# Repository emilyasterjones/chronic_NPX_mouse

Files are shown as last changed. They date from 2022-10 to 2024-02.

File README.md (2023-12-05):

# chronic_NPX_mouse
Build files for chronic, recoverable Neuropixels 1.0 or 2.0 implants in mice. Used in [this protocol collection](dx.doi.org/10.17504/protocols.io.e6nvwjo87lmk/v2).

Chronic recoverable implant based off of [(Juavinett et al, 2019)](https://elifesciences.org/articles/47188) and modified by Janna Aarse, who generously shared her build files with me to modify.

**Components**
* Body piece (single for 1.0 probes, left and right for dual 2.0 probes)
* Wing (attaches to body with screw & nut)
* Flex holders (go around the PCB and lower part of flex cable)
* Dome (covers side of shanks opposite the wings)
* Headstage holder
* **NEW** Lower profile headstage holder (see 2.1 design folder). This holder sits behind the implant, so the attachments during surgery are substantially shorter (at the expense of losing LED tracking). The holder is mounted during surgery (adds .14g), and you can choose to attach the headstage during surgery as well (adds a total of 1.04g). During recording, simply plug in the Omnetics connector. Optionally, hook a paper clip (attached to a counterweighted pulley) into the hole to relieve some of the weight during recording.

**Versions**
* Single 1.0 probe
* Dual 2.0 beta probes
* Dual 2.0 probes (same as beta probe files, just with updated flex holders and headstage holder by Frances Cho and probe + headstage files from Neuropixels)
* 2.1 design (same as 2.0 builds, but I will be updating these files over time as I test new versions). 

**Possible modifications**
* If you don't need LED tracking, you can remove the arms of the headstage holder.
* Body pieces can attach to either side of the probe and at any height. You can also mount the body pieces at any angle, though the wing pieces are rounded so that angling the body piece is unnecessary, even at extreme angles of insertion.
* All flex holders, except for flex holder #1 (with tab slot), are optional. If your probes are very close together, you can skip the flex holders (except holder #1) and just cover the wires and PCB with electrical tape.
* If your probes are angled towards each other such that the body pieces might collide, you can (1) attach a dovetail as a shim under the body piece to move it away, (2) mount the body piece farther to the side of the probe, or (3) angle the wing holder portion away from the probe. See the angled body piece example in the 2.0 probe folder.

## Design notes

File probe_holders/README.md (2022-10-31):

Dovetail cap made to official Neuropixels specs: https://e2f49b05-3010-45e2-a7bf-b8f67811425a.filesusr.com/ugd/832f20_1617705787d84f7795ec85aa08630ea1.pdf

NOTE: the machined dovetail holder adapter is the inverted; should be a tapped hole not an outward screw

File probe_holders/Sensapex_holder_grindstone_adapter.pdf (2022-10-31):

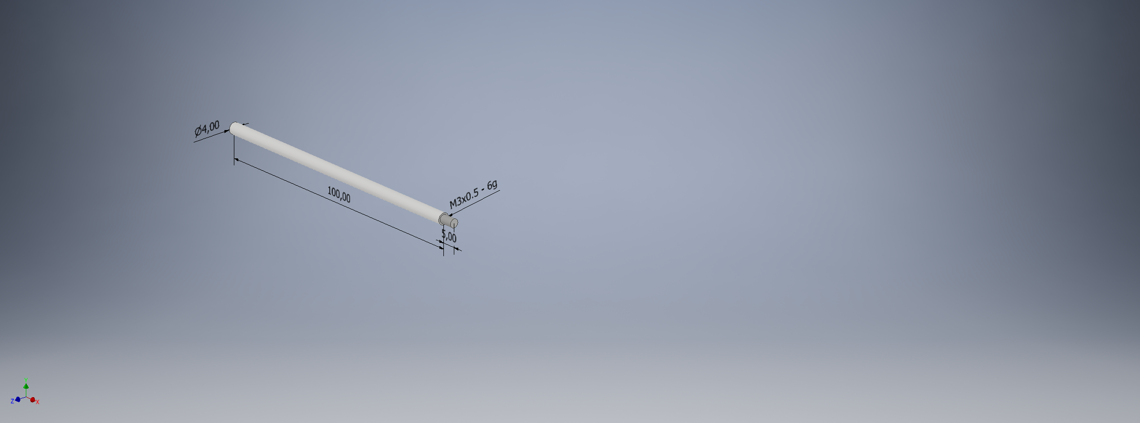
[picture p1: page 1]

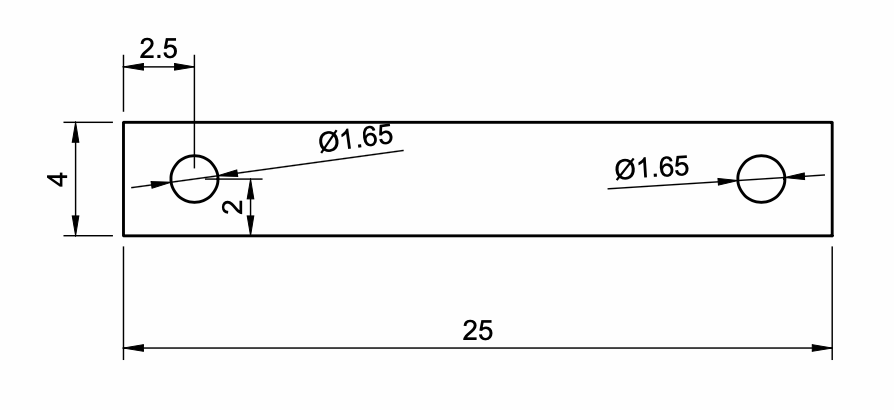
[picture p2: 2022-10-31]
accessories/Headbar_specs.png

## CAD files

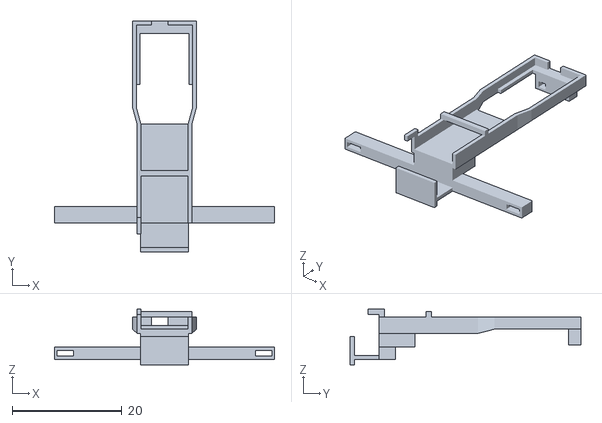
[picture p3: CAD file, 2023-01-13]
2.0_beta_probes/Headstage_holder.stl
40.0 x 42.0 x 10.1

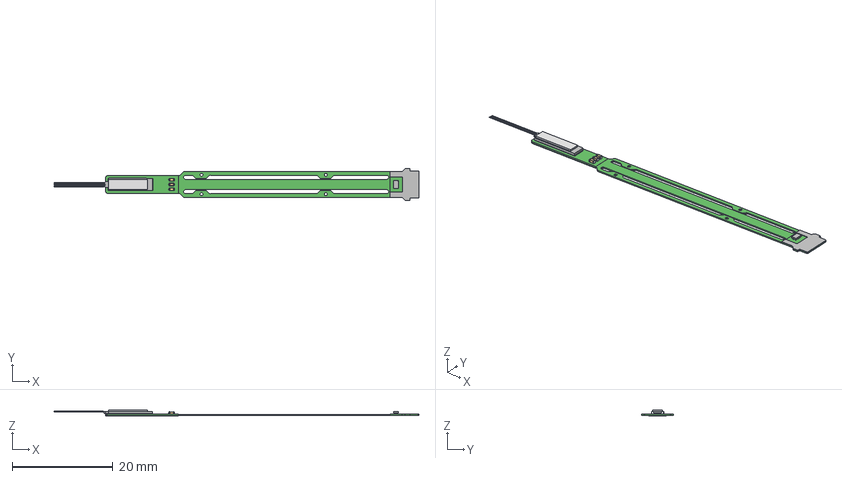
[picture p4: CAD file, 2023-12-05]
2.0_probe/Probe.step
72.4 x 6.40 x 1.23 mm
VCSP50L1_ROM_edit_RGB8421504
Extruded x 9
CerCap_0402 x 3

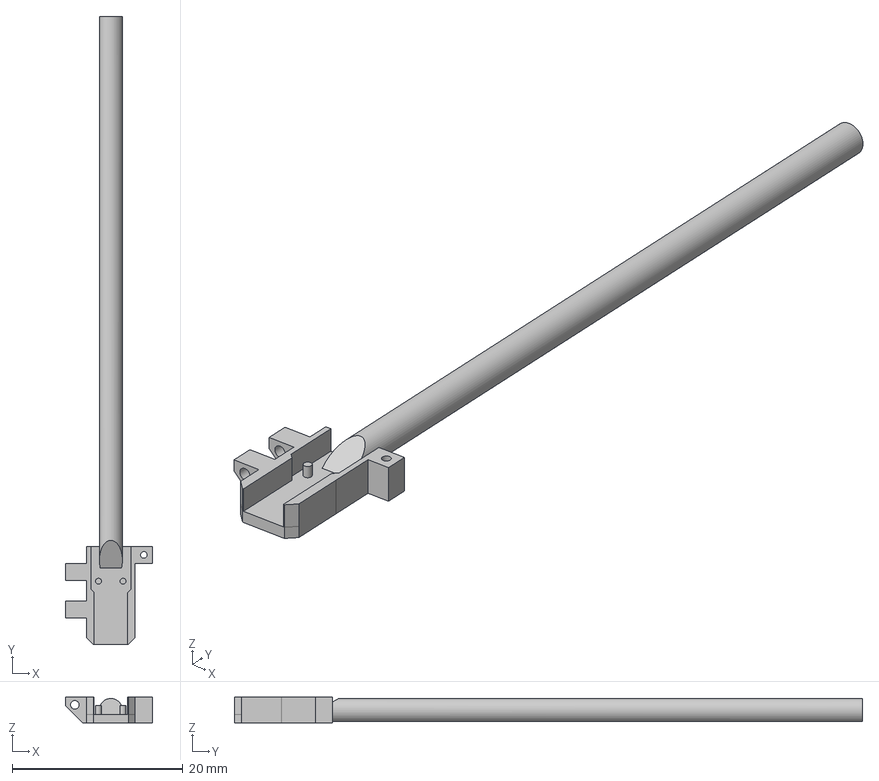
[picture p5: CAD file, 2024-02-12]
2.1_design/20_probe_clamp_lower.step
10.1 x 73.5 x 3.00 mm

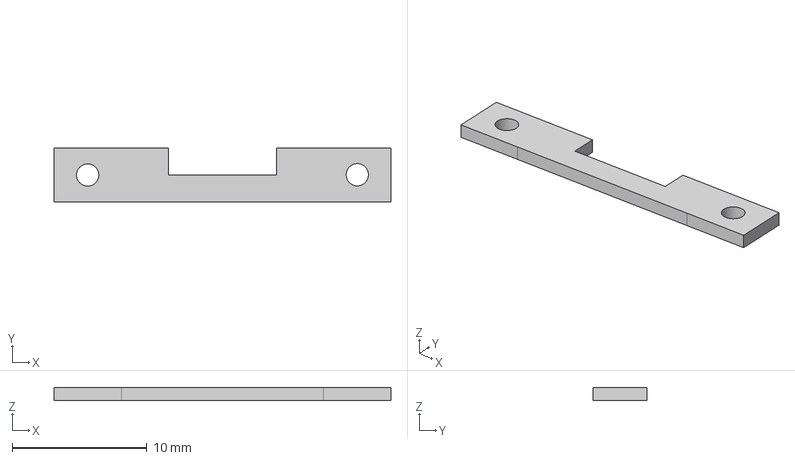
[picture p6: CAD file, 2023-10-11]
accessories/Headbar_notch.step
25.0 x 4.00 x 1.00 mm

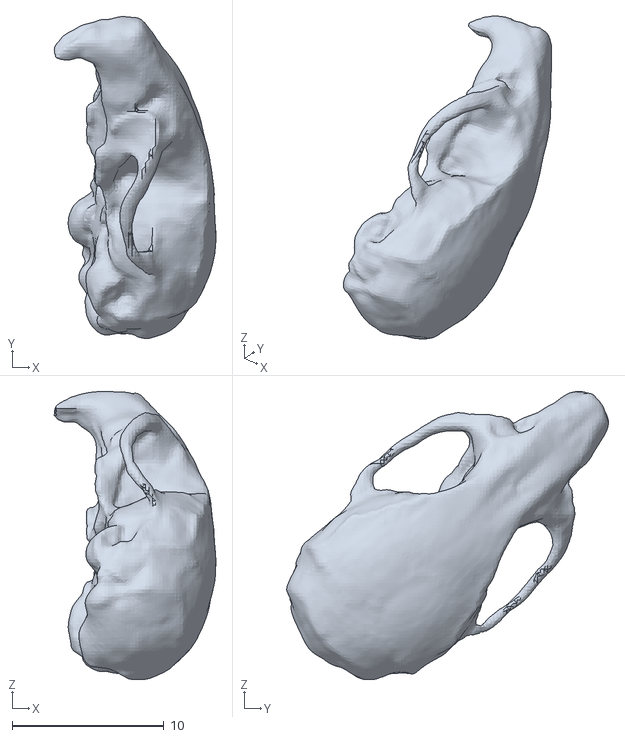
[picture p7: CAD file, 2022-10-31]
accessories/Mouse skull and brain/ONECore_Mouse_Skull_v0.stl
10.7 x 21.2 x 19.0

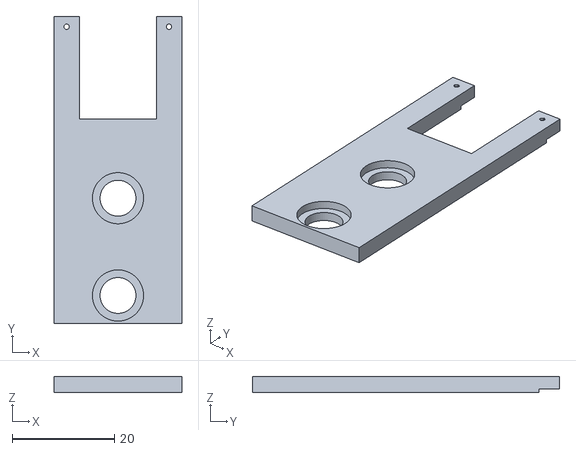
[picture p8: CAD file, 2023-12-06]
headforks/Headfork_for_nonimplanted_mice.stl
25.0 x 60.0 x 3.20

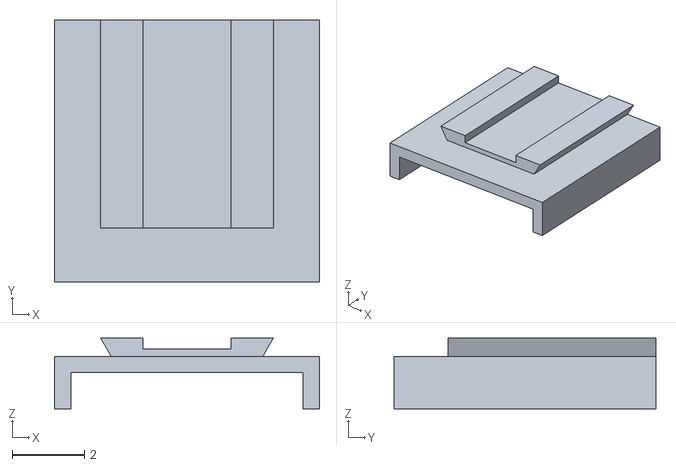
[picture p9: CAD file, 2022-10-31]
probe_holders/Dovetail_to_specs v2.stl
7.33 x 7.26 x 1.96

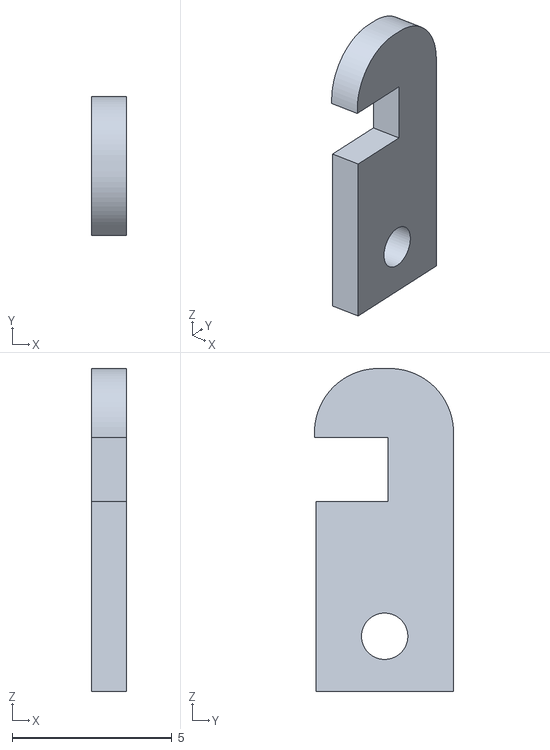
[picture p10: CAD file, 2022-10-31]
1.0_probe/Wings.stl
1.10 x 4.35 x 10.1

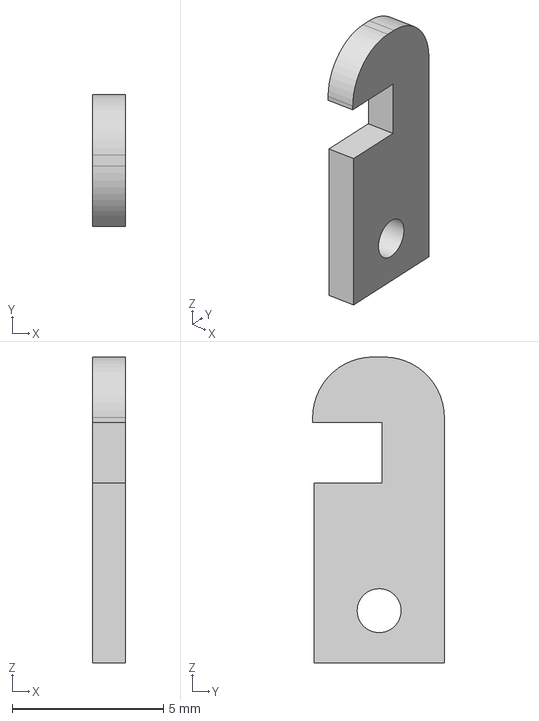
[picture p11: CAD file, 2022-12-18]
2.0_beta_probes/Wings.step
1.10 x 4.35 x 10.1 mm

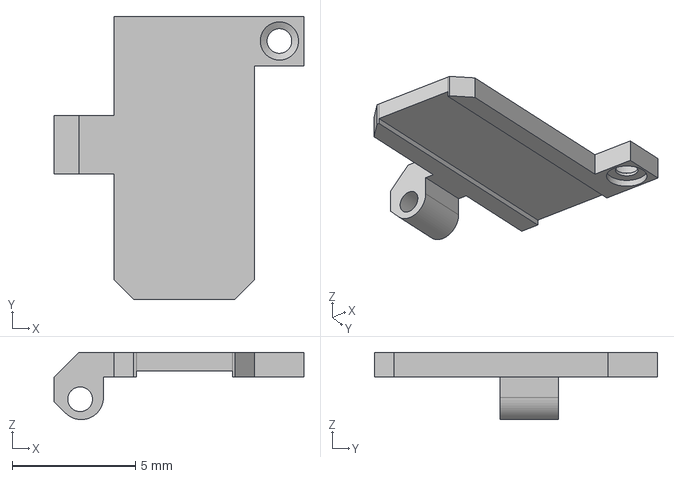
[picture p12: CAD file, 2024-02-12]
2.1_design/20_probe_clamp_upper.step
10.1 x 11.5 x 2.73 mm

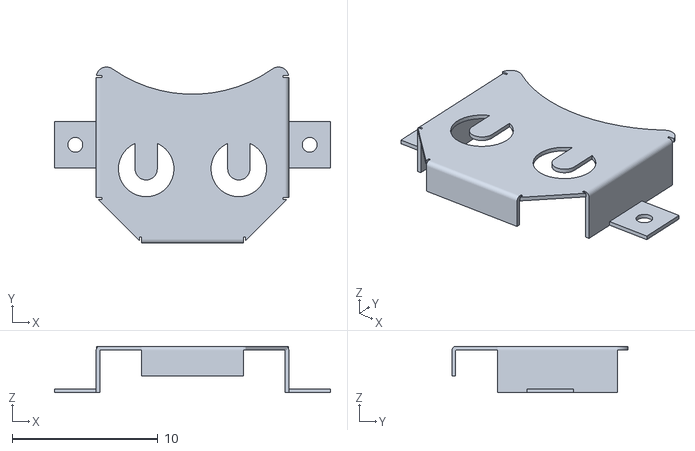
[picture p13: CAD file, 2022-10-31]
accessories/BATTCON_12MM.STL
18.9 x 12.1 x 3.17

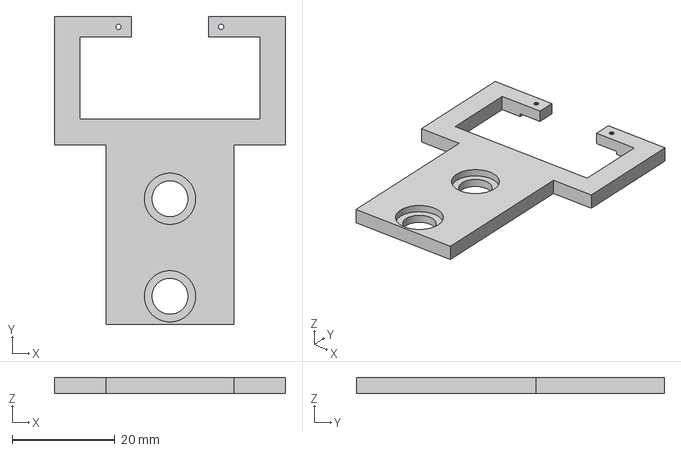
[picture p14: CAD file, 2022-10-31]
headforks/Headfork_for_chronic.step
45.0 x 60.0 x 3.20 mm

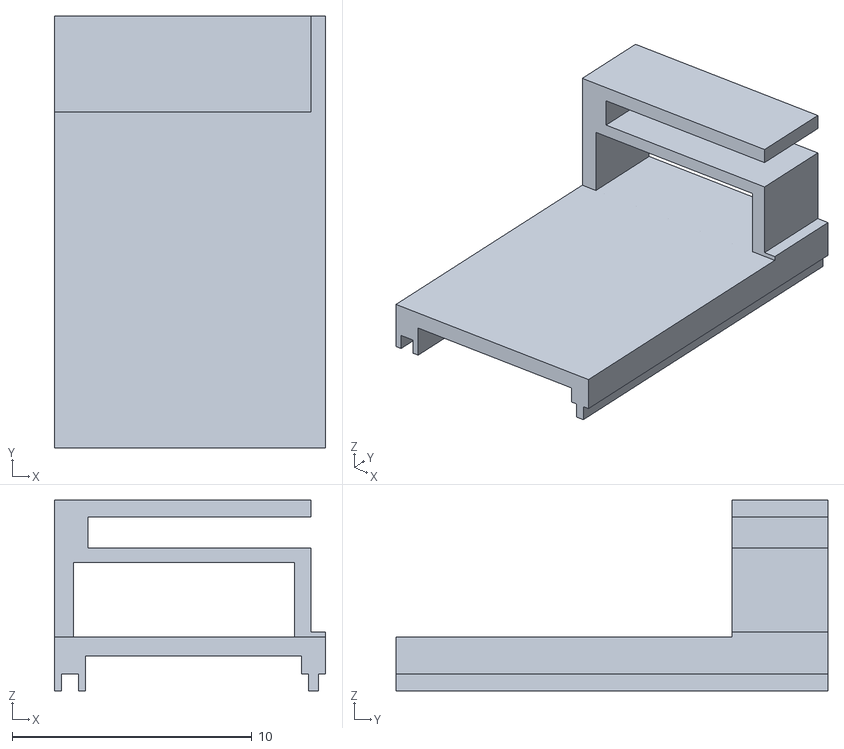
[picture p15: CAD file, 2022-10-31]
1.0_probe/Flex_holder_1.stl
11.3 x 18.0 x 7.96

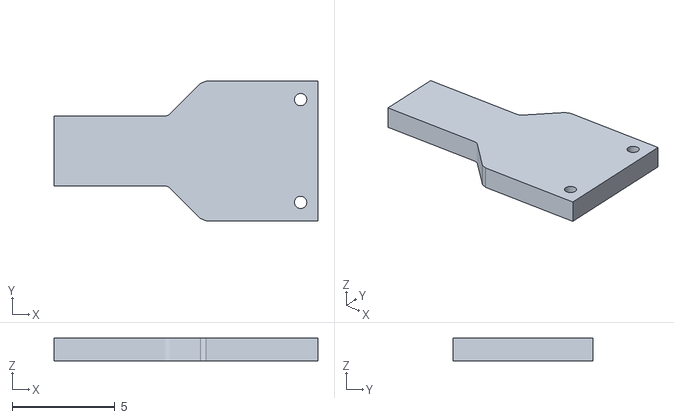
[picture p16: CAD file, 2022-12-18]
2.0_beta_probes/PCB.stl
12.8 x 6.80 x 1.10

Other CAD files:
2.0_probe/Headstage_holder.stl
2.0_probe/Flex_holder_1.stl
2.1_design/20_probe_clamp_hinge_pin.step
accessories/Battery Breakout.stl
1.0_probe/Body_piece_with_screw.f3d
1.0_probe/Body_piece_with_screw.stl
1.0_probe/Dome.f3d
1.0_probe/Dome.stl
1.0_probe/Flex_holder_1.f3d
1.0_probe/Flex_holder_1_with_screw.f3d
1.0_probe/Flex_holder_1_with_screw.stl
1.0_probe/Flex_holder_2.f3d
1.0_probe/Flex_holder_2.stl
1.0_probe/Headstage_holder.f3d
1.0_probe/Headstage_holder.stl
1.0_probe/Wings.f3d
2.0_beta_probes/Body_piece_left.f3d
2.0_beta_probes/Body_piece_left.stl
2.0_beta_probes/Body_piece_right.f3d
2.0_beta_probes/Body_piece_right.stl
2.0_beta_probes/Dome.f3d
2.0_beta_probes/Dome.stl
2.0_beta_probes/Dovetail.stl
2.0_beta_probes/Flex_holder_1.f3d
2.0_beta_probes/Flex_holder_1.stl
2.0_beta_probes/Flex_holder_2.f3d
2.0_beta_probes/Flex_holder_2.stl
2.0_beta_probes/Flex_holder_2_with_dovetail.f3d
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

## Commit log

2022-10-31 Initial commit from private repo
    [BATTCON_12MM.STL, Battery Breakout.stl, Body_piece_with_screw.f3d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]
2022-12-08 Initial commit of dual-probe NPX 2.0 beta design
    [Body_piece_left.f3d, Body_piece_left.stl, Body_piece_right.f3d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]
2022-12-11 Fit improvements after first print test
    - headstage holder fixes to match actual headstage
    - headstage holder now fits battery breakout board without switch + S bend for both probes to make shorter
    - flex holders better fit for probe PCB
    [Flex_holder_1.f3d, Flex_holder_1.stl, Flex_holder_2.f3d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]
2022-12-18 Modifications based on pilot surgery
    [Dome.f3d, Dome.stl, Flex_holder_1.f3d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]
2023-01-13 Adding full 2.0 beta probe print for protocol release
    [Headstage_holder.f3d, Headstage_holder.stl, Headstage_holder_view_with_accessories.f3d]
2023-10-11 adding notched headbar
    [Headbar_notch.f3d, Headbar_notch.step]
2023-11-23 2.1 updates & README updates
    * reorganize files into folders per version
    * add 2.1 design
    * add details to README about modificaitons
    [Body_piece_left.f3d, Body_piece_left.stl, Body_piece_right.f3d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]
2023-11-28 Adding flex holder with HS incorporated
    [Flex_holder_1_with_headstage.f3d, Flex_holder_1_with_headstage.stl, Headstage_dust_cover.f3d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]
2023-12-05 Adding 2.0 real probe designs + 2.1 designs
    - 2.0 real probe files
    - 2.0 probes & heastages
    - dome for implanting single 2.0 probe
    - on-mouse headstage holder (wide and narrow) for 2.0 beta and real probes
    - angled body piece
    [Body_piece_right_30deg.f3d, Body_piece_right_30deg.stl, Dome_single_probe.f3d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]
2023-12-06 Adding headfork for nonimplanted mice
    [Headfork_for_nonimplanted_mice.f3d, Headfork_for_nonimplanted_mice.stl]
2023-12-22 Adding custom machined probe holder
    [20_probe_clamp_lower.step, 20_probe_clamp_upper.step]
2024-02-12 Updating the probe clamp
    [20_probe_clamp_hinge_pin.step, 20_probe_clamp_lower.step, 20_probe_clamp_upper.step]
